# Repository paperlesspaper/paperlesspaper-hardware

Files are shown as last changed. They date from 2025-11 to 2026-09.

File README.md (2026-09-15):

### [paperlesspaper](https://paperlesspaper.de/en) e-Paper Photo Frame Hardware

Here you will find all source files of our PCB design and hardware CAD files used for the [paperlesspaper](https://paperlesspaper.de/en) ePaper photo frame which has a Spectra 6 color EInk display.

[Documentation about manufacturing the parts](https://docs.paperlesspaper.de/manufacturing/overview)

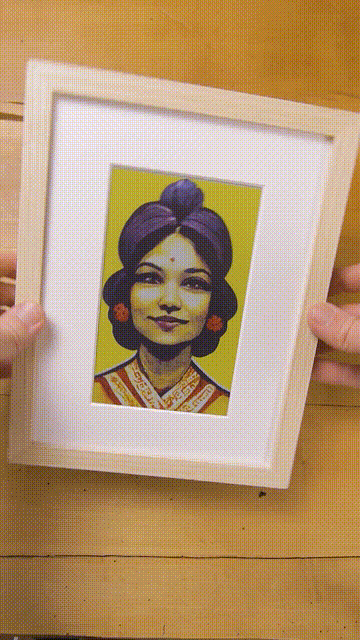
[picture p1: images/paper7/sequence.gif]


There is also a short [blog post](https://paperlesspaper.de/en/blog/open-hardware) available.

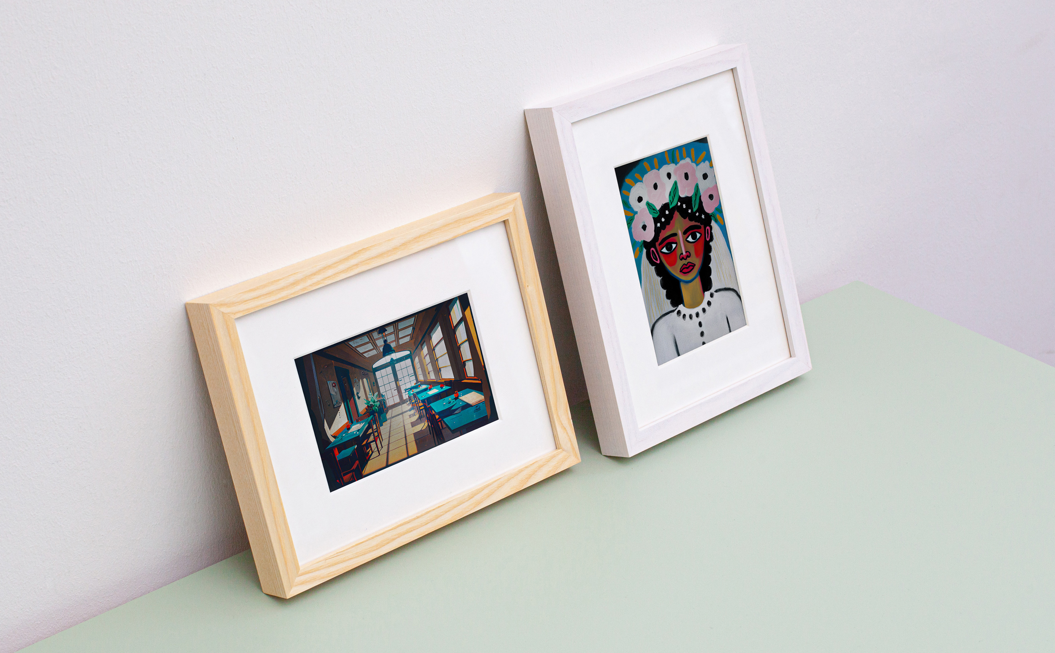
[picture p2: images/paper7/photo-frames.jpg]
pcb side by side (https://paperlesspaper.de/en)


### What you need

Software:

- [Autodesk Fusion 360](https://www.autodesk.com/de/education/edu-software/fusion) (free version is good enough, for everything except PCB)
- Adobe Illustrator (only for the laser of the backside)

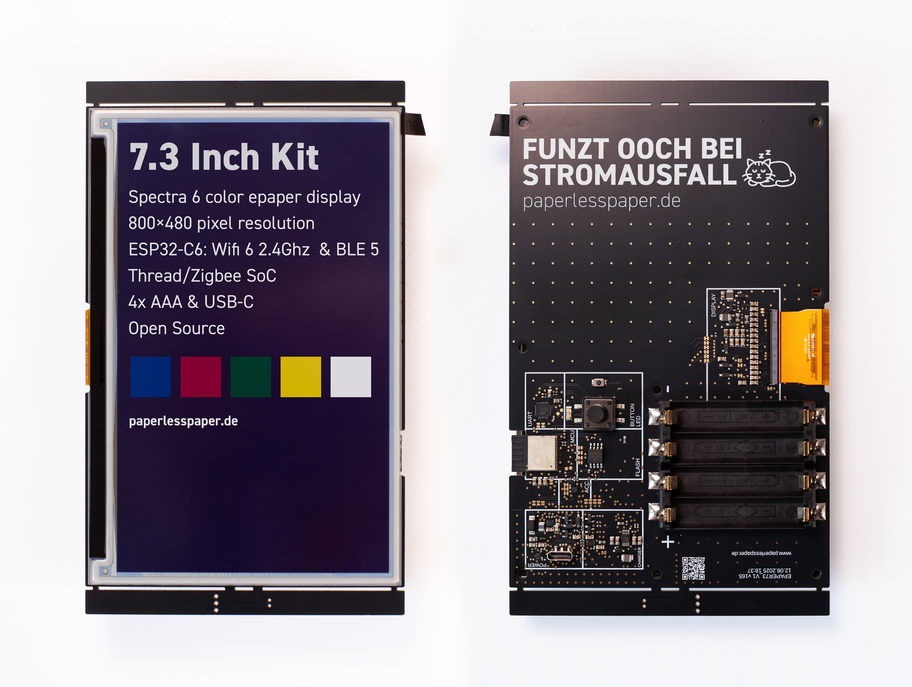
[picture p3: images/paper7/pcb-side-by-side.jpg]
pcb side by side


Manufacture:

- 3D printer (for battery holder and for fixtures/carriers)
- laser cutter (or CNC) for back panel of the photo frame
- manufacturer like JLCPCB for the PCB (more info soon)

Hardware:

- Standard picture-frame with turn buttons or spring clips

### Source files

| Model | Hardware files |
| --- | --- |
| Paper 7 / OpenPaper 7 | [paper7/](./paper7/) — PCB, Fusion CAD, fixtures, laser-cut files and STL parts |
| OpenPaper L (13.3-inch) | [paperl/](./paperl/) — Fusion assembly, PCB sources, manufacturing archive, laser-cut files and STL parts |

See the [OpenPaper L hardware guide](./paperl/README.md) for file descriptions, source versions and manufacturing notes.

### Paper 7 / OpenPaper 7

The following files can be found inside [/paper7](./paper7/).

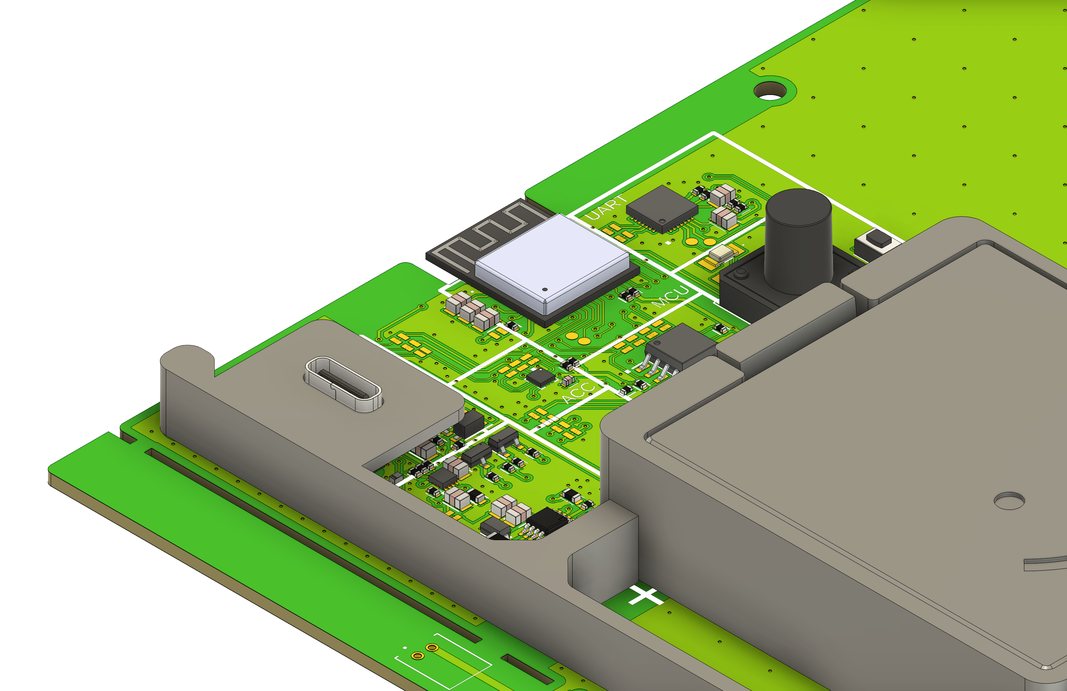
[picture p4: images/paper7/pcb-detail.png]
detail image of the pcb


#### [pcb/](./paper7/pcb/)

PCB design source files and manufacturing exports for the Paper 7 board.

- [EPAPER73_V2.fsch](./paper7/pcb/EPAPER73_V2.fsch) and [EPAPER73_V2.fbrd](./paper7/pcb/EPAPER73_V2.fbrd): schematic and board source files for Autodesk Fusion Electronics.
- [EPAPER73_V2_sch.jpg](./paper7/pcb/EPAPER73_V2_sch.jpg) and [EPAPER73_V2_pcb.jpg](./paper7/pcb/EPAPER73_V2_pcb.jpg): preview images of the schematic and PCB layout.
- [paper7_v2_gerber.zip](./paper7/pcb/paper7_v2_gerber.zip): Gerber and drill files for PCB fabrication, including copper, soldermask, silkscreen, solderpaste, profile and drill layers.
- [epaper-bom-V2.xlsx](./paper7/pcb/epaper-bom-V2.xlsx): bill of materials for PCB assembly.
- [epaper-pp-V2.xlsx](./paper7/pcb/epaper-pp-V2.xlsx): pick-and-place / component placement file for PCB assembly.
- [EPAPER73_V2.3mf](./paper7/pcb/EPAPER73_V2.3mf): 3D export of the PCB for mechanical checks and fit validation.

Use the Gerber zip together with the BOM and pick-and-place spreadsheet when ordering an assembled PCB. Use the `.fsch` and `.fbrd` files if you want to inspect or modify the design.

#### [paper-7-inside.f3z](./paper7/paper-7-inside.f3z)

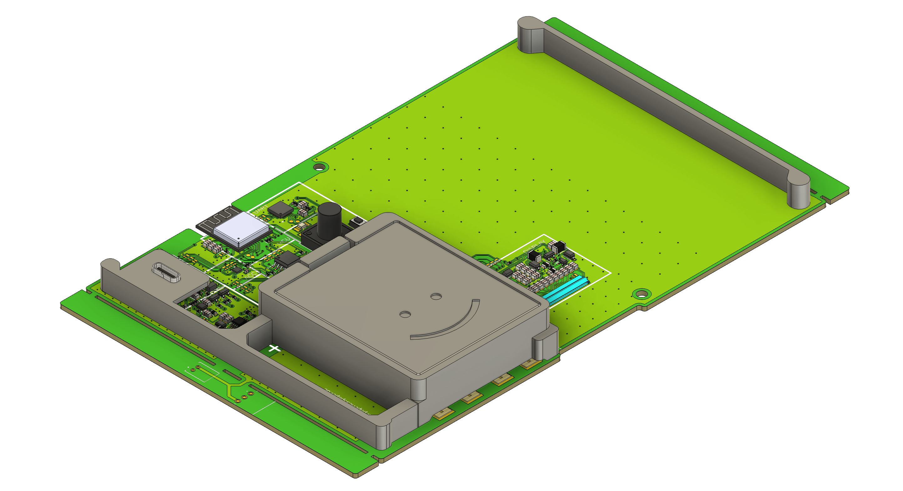
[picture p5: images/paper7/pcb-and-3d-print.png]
detail image of the pcb


The inner carrier (sub-frame) that the PCB attaches to. Contains the PCB and 3D printed parts for USB connector, battery holder and distance elements.

#### [paper-7-picture-frame.f3z](./paper7/paper-7-picture-frame.f3z)

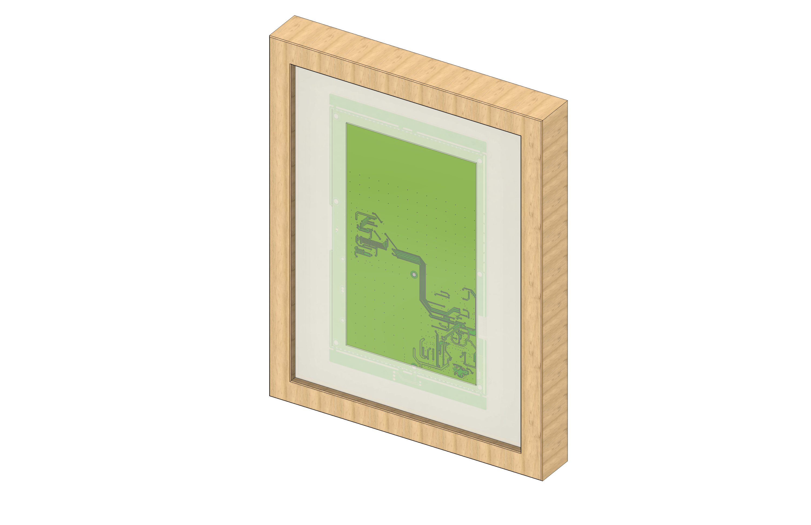
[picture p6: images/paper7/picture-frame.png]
detail image of the pcb


The picture frame. Used to create the laser cut on the backside. Fits the "inside".

#### [paper-7-passepartout-appliance-fixture.f3z](./paper7/paper7-passepartout-applicance-fixture.f3z)

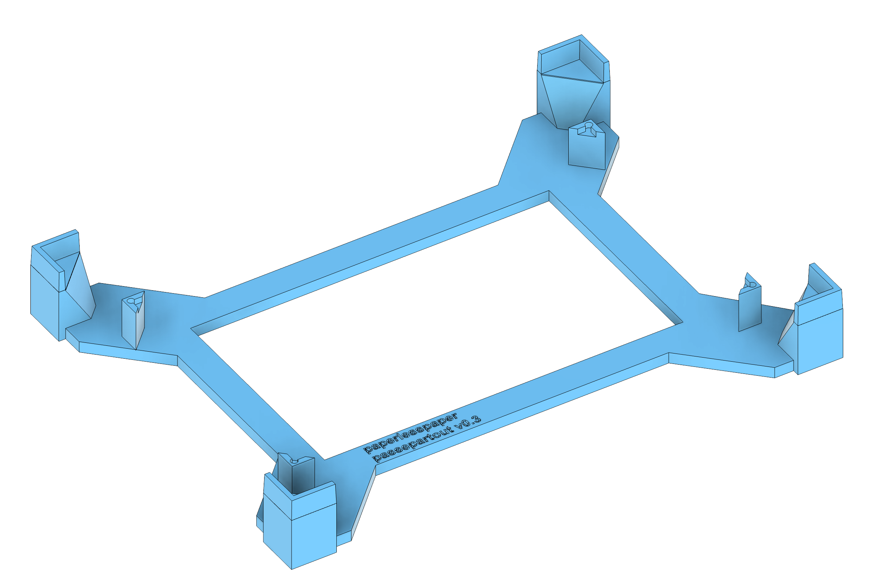
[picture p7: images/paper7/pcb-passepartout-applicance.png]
detail image of the pcb


A slimmer jig for aligning the display with a passe-partout / mat.
Ensures the visible window is perfectly centered and parallel.

#### [paper7-display-appliance-fixture.f3z](./paper7/paper7-display-appliance-fixture.f3z)

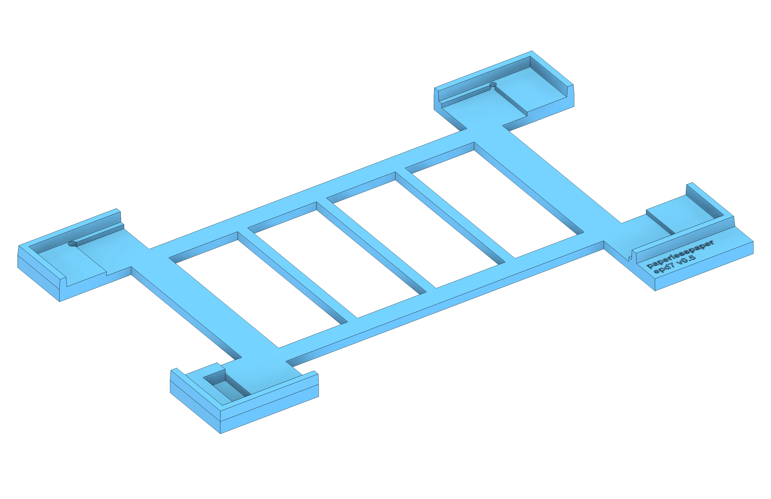
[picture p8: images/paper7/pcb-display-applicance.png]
detail image of the pcb


A jig to hold the display/appliance while you bond it. Keeps the panel centered relative to the frame opening.

#### [lasercut/Lasercut-back-generic.ai](./paper7/lasercut/Lasercut-back-generic.ai) and [.svg](./paper7/lasercut/Lasercut-back-generic.svg)

The lasercut source files to create the backside of the picture frame.

Color mapping: `red: cut`, `black: mark`, `green: ignore`

#### 3D print (battery compartment & spacers)

For the 3D printed files you can find the replacement parts also at [Makerworld](https://makerworld.com/de/models/1668788-paper-7-battery-compartment#profileId-1766474).
The recommended material is PETG. There are no screws needed. Only the battery cover needs to be glued for better durability. Use regular superglue to glue it.

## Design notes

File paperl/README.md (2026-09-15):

# OpenPaper L hardware

Hardware files for the 13.3-inch OpenPaper L e-Paper photo frame. This directory follows the [Paper 7 hardware](../paper7/) structure, with Fusion CAD, printable replacement parts, PCB sources and back-panel laser templates.

## Fusion CAD

| Front | Back (battery cover hidden) |
| --- | --- |
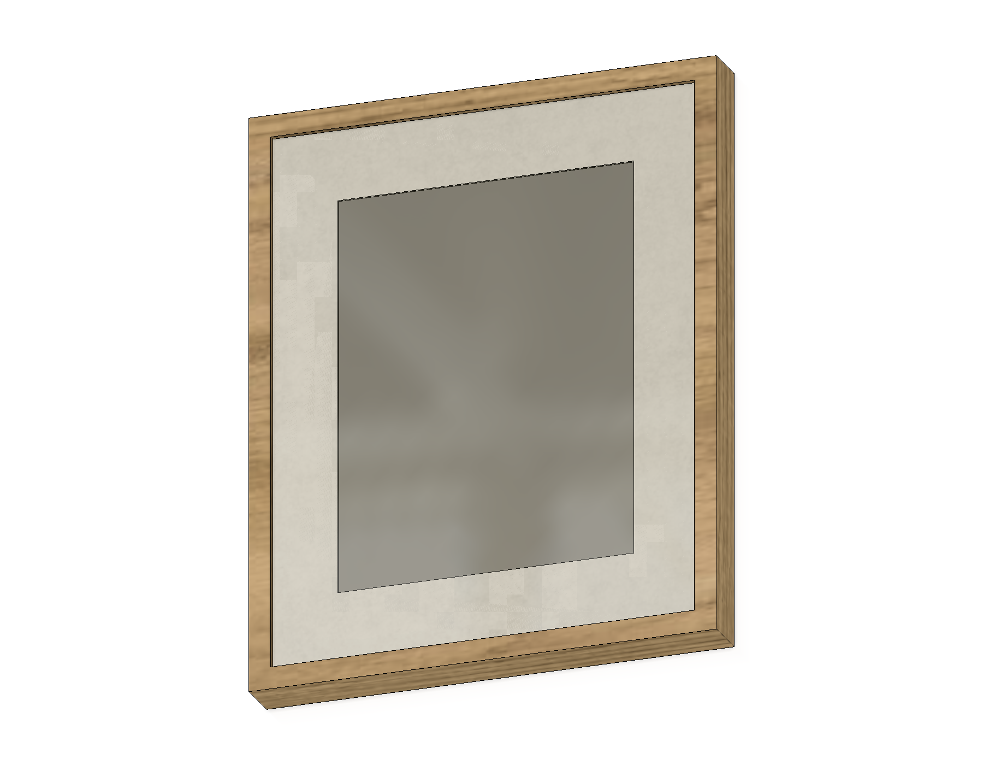
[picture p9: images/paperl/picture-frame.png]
OpenPaper L front
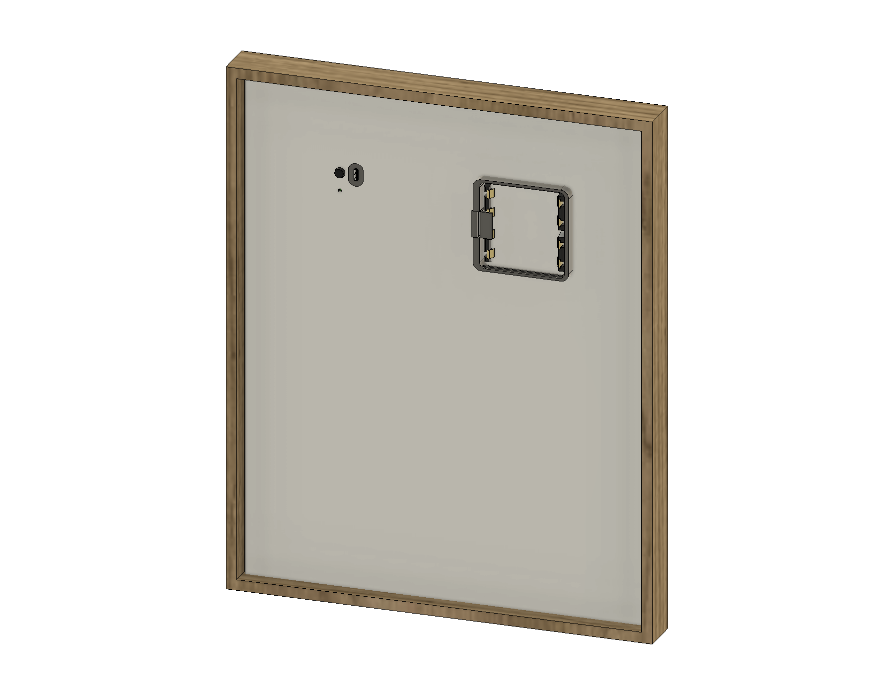
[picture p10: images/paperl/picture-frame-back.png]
OpenPaper L back
|  |  |

- [paper-l-picture-frame.f3z](./paper-l-picture-frame.f3z): complete **OpenPaper L Bilderrahmen** assembly, including the wooden frame, glass, passe-partout, back panel, internal carrier, PCB and display references.

Upload the `.f3z` archive through Fusion's data panel to import its linked designs together. The inner assembly is named **OpenPaper L inside 3**. It contains the battery compartment, cover, corner spacer, spring and USB holder. The display reference retains its original Fusion name, **DEK 13.3 inch panel**.

The archive was exported on **2026-09-14** after updating and saving the linked Fusion references:

| Fusion design | Version in the archive |
| --- | --- |
| OpenPaper L Bilderrahmen | 11 |
| OpenPaper L inside 3 | 10 |
| EPAPER133_V2 (3D PCB) | 8 |
| DEK 13.3 inch panel | 4 |

## 3D print

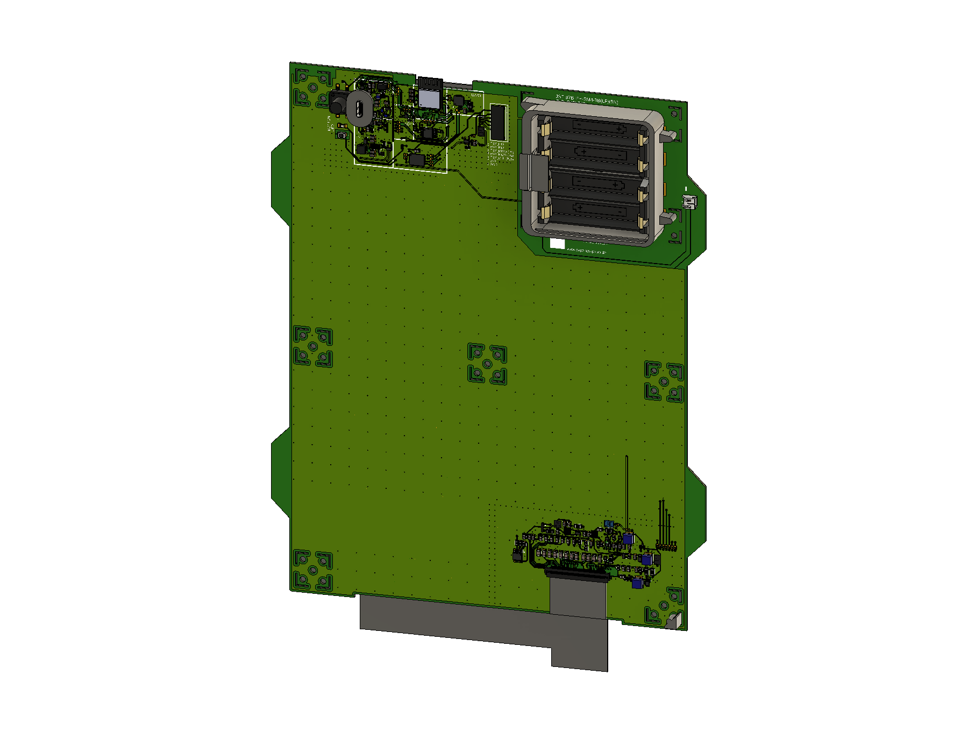
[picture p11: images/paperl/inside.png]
OpenPaper L inner assembly


The [stl/](./stl/) files were exported from the above picture-frame assembly in **millimetres**, using binary STL and Fusion's high mesh refinement. Each file contains one part, without the hidden battery-compartment context body.

| File | Fusion component | Bounding box in mm (X × Y × Z) |
| --- | --- | --- |
| [Battery compartment](./stl/paper-l-BatteryCompartment.stl) | Batteriefach v2  | 82.196 × 71.700 × 19.500 |
| [Battery cover](./stl/paper-l-BatteryCover.stl) | Deckel | 65.284 × 64.699 × 3.200 |
| [Corner spacer](./stl/paper-l-Corner.stl) | Corner | 6.605 × 6.605 × 10.000 |
| [Spring](./stl/paper-l-Spring.stl) | Spring | 15.500 × 19.800 × 9.500 |
| [USB holder](./stl/paper-l-USBHolder.stl) | USB holder | 14.300 × 20.080 × 6.500 |

Choose orientation, material and the required number of copies in your slicer for the assembly being built. The dimensions above describe the CAD coordinate orientation, not a recommended print orientation.

## PCB

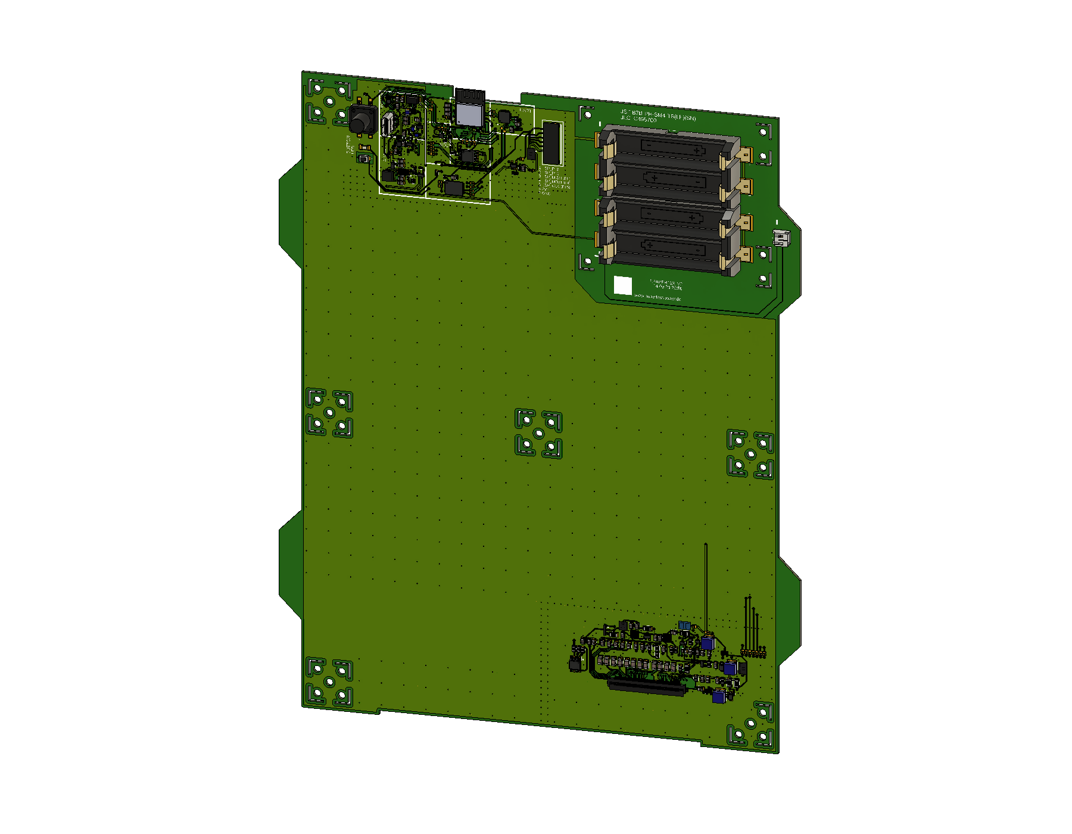
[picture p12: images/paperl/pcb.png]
OpenPaper L PCB


- [EPAPER133_V2.fsch](./pcb/EPAPER133_V2.fsch): native Fusion Electronics schematic, version 5.
- [EPAPER133_V2.fbrd](./pcb/EPAPER133_V2.fbrd): native Fusion Electronics board, version 13, matching the 2D-board reference recorded in the exported 3D PCB.
- [EPAPER133_V2.3mf](./pcb/EPAPER133_V2.3mf): 3D PCB mesh exported from the updated picture-frame assembly (PCB version 8).
- [Schematic preview](../images/paperl/fsch.png) and [board preview](../images/paperl/fbrd.png): embedded previews from the respective native source files.
- [manufacturing-2026-08-17/](./pcb/manufacturing-2026-08-17/): the existing fabrication batch, containing [Gerber/drill files](./pcb/manufacturing-2026-08-17/paper-l-v2-gerber.zip), [BOM](./pcb/manufacturing-2026-08-17/EPAPER133_V2.csv) and [front-side pick-and-place data](./pcb/manufacturing-2026-08-17/PnP_EPAPER133_V2_front.csv).

## Laser-cut back panel

The [lasercut/](./lasercut/) directory contains the existing production templates, with separate machine layouts:

| Layout | Illustrator source | SVG | SVG canvas |
| --- | --- | --- | --- |
| Zing | [AI](./lasercut/zing/Lasercut-back-zing.ai) | [SVG](./lasercut/zing/Lasercut-back-zing.svg) | 610 × 400.54 mm |
| Lasersaur | [AI](./lasercut/lasersaur/Lasercut-back-lasersaur.ai) | [SVG](./lasercut/lasersaur/Lasercut-back-lasersaur.svg) | 1100 × 570 mm |

Color mapping: **red = cut**, **black = mark**, **green = ignore / alignment**. These layouts position cutouts and markings on existing frame backs; the canvas size is the machine layout size, not the size of a single back panel. Preserve the SVG's physical units when importing.

The laser files are the existing May 2026 production files. Check the battery and USB openings against your frame back before cutting. Machine power/speed presets are not included.

## Source provenance

| Repository files | Original source |
| --- | --- |
| Fusion archive and STL files | Autodesk Fusion: `OpenPaper L Bilderrahmen`, exported 2026-09-14 after reference update |
| PCB `.fsch` / `.fbrd` | Fusion's local native source snapshots, schematic v5 and board v13; the latter is referenced by the archived 3D PCB |
| August Gerber, BOM and pick-and-place files | `Hardware/PCB/CAM133/V2/EPAPER133_V2_2026-08-17.zip` |
| Zing AI | `OpenPaper L/Aktuell Zing/OpenPaper L Rückseite-Zing2.ai` (2026-05-28) |
| Zing SVG | `OpenPaper L/Aktuell Zing/OpenPaper L Rückseite-Zing.svg` (2026-05-26) |
| Lasersaur AI | `OpenPaper L/Aktuell Lasersaur/Laservorlage-Saur3.ai` (2026-05-28) |
| Lasersaur SVG | `OpenPaper L/Aktuell Lasersaur/Laservorlage-Saur2.svg` (2026-05-26) |

For the existing manufacturing overview, see the [project documentation](https://docs.paperlesspaper.de/manufacturing/overview).

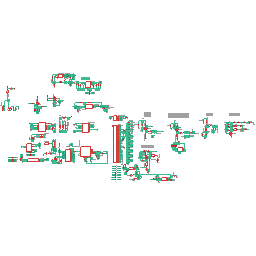
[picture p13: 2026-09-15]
images/paperl/fsch.png

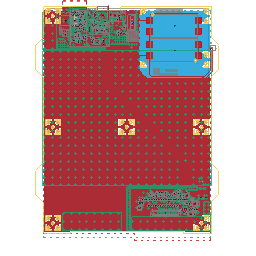
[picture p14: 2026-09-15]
images/paperl/fbrd.png

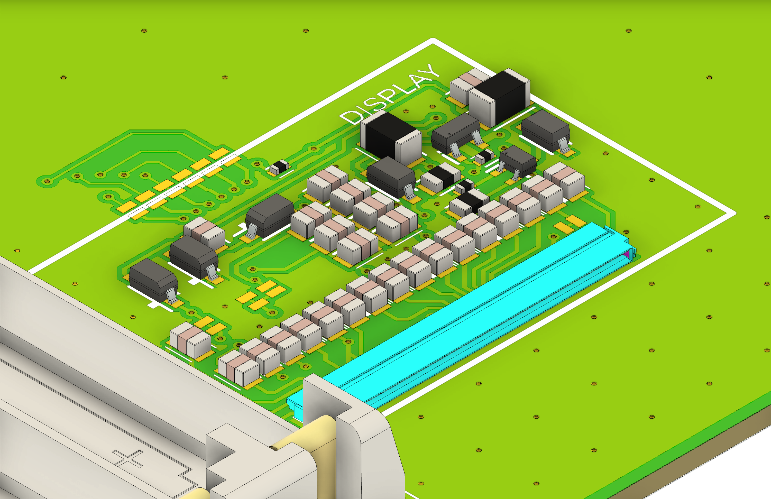
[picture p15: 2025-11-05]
images/paper7/pcb-detail-display.png

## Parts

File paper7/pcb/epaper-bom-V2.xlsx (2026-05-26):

Qty | Comment | Device | Footprint | Designator | JLCPCB Part # | Description
16 | 10uF 25V 0805 | C_CHIP-0805(2012-METRIC) | CAPC2012X110 | C1, C3, C8, C11, C12, C13, C14, C15, C16, C30, C31, C33, C38, C46, C49, C50 | C15850 | Capacitor - Generic
1 | 470nF 25V 0805 | C_CHIP-0805(2012-METRIC) | CAPC2012X110 | C10 | C13967 | Capacitor - Generic
6 | 1uF 50V 0805 | C_CHIP-0805(2012-METRIC) | CAPC2012X110 | C17, C18, C20, C21, C22, C23 | C28323 | Capacitor - Generic
1 | 2.2uF 25V 0805 | C_CHIP-0805(2012-METRIC) | CAPC2012X110 | C19 | C377773 | Capacitor - Generic
5 | 1uF 25V 0805 | C_CHIP-0805(2012-METRIC) | CAPC2012X110 | C2, C6, C39, C40, C47 | C28323 | Capacitor - Generic
1 | 470nF 50V 0805 | C_CHIP-0805(2012-METRIC) | CAPC2012X110 | C24 | C13967 | Capacitor - Generic
1 | 10uF 50V 0805 | C_CHIP-0805(2012-METRIC) | CAPC2012X110 | C26 | C440198 | Capacitor - Generic
4 | 100nF 25V 0402 | C_CHIP-0402(1005-METRIC) | CAPC1005X60 | C35, C42, C44, C48 | C307331 | Capacitor - Generic
7 | 4.7uF 25V 0805 | C_CHIP-0805(2012-METRIC) | CAPC2012X110 | C4, C5, C9, C28, C29, C36, C37 | C1779 | Capacitor - Generic
2 | 1nF 25V 0402 | C_CHIP-0402(1005-METRIC) | CAPC1005X60 | C41, C45 | C1523 | Capacitor - Generic
5 | 100nF 50V 0805 | C_CHIP-0805(2012-METRIC) | CAPC2012X110 | C7, C25, C27, C32, C34 | C28233 | Capacitor - Generic
3 | LESD5D5.0CT1G | LESD5D5.0CT1G | LESD5D50CT1G | D1, D2, D3 | C5199850 | Transient Voltage Suppressors for ESD Protection
1 | PMEG2010AEH | PMEG2010AEH | SODFL3516X120N | D10 | C110921 | Diode Schottky 20V 1A,PMEG2010AEH NXP PMEG2010AEH Schottky Diode, 1A, 20V, 2-Pin SOD123F
1 | SS34 | SS34 | DIOM5327X244N | D12 | C8678 | SMD Schottky Diode
2 | CUS08F30 | CUS08F30 | CUS357H3F | D4, D13 | C27636112
4 | MBR0530T1G | MBR0530 | SOD3716X135N | D5, D6, D7, D8 | C82046 | Compact Surface Mount Package with The Same Footprint as Mini-melf; Schottky Rectifier, 0.5A, 30V in SOD-123 Package
2 | BH-AAA-B5AA001 | 1078 | 1078 | H1, H2 | C964881 | Cylindrical Battery Contacts, Clips, Holders & Springs AAA dual holder w/ coil Spring SMT
1 | W25Q128JVSIQ | W25Q128JVSIQ | SOIC127P790X216-8N | IC1 | C97521 | 128M-bit Serial Flash Memory with uniform 4KB sectors and Dual/Quad SPI
1 | CP2102N-A02-GQFN28R | CP2102N-A02-GQFN28R | QFN50P500X500X80-29N | IC2 | C964632 | USB Interface IC USB to UART bridge - QFN28
1 | BQ25172DSGR | BQ25172DSGR | SON50P200X200X80-9N | IC4 | C5189434 | Battery Management 0.8-A, one- to six-cell NiMH stand-alone linear charger in a QFN package
1 | DMP2035U | DMP2035U | SOT96P240X115-3N | IC5 | C110499 | MOSFET, P CH, ESD,-20V,-3.6A, SOT23
1 | TPS61085DGKR | TPS61085DGKR | SOP65P490X110-8N | IC6 | C113659 | 18.5V, 2A, 650kHz / 1.2MHz Step-Up DC-DC Converter w/ Forced PWM Mode
1 | U263-241N-4BQC02 | U263-241N-4BQC02 | U263241N4BQC02 | J1 | C2689742 | 3.1TYPE-C connector female 24P upright
1 | FPC-05FB-50PH20 | FPC-05FB-50PH20 | FPC05FB50PH20 | J5 | C2856838
2 | 10uH/1A (20%) | CUSTOMINDUCTORSBCIHP0420SC-100M | BCIHP0420SC-100M | U$1, U$3 | C2921170 | Inductor Fixed - Generic
1 | 2.2uH/1A (20%) LQM2HPN2R2MG0L | L_CHIP-1008(2520-METRIC) | INDC2520X120N | L3 | C86092 | Inductor Fixed - Generic
1 | 3.3uH 1.5A | CUSTOMINDUCTORSSL0420-3R3M | SL0420-3R3M | U$2 | C22463807 | Inductor Fixed - Generic
1 | KPTD-3216SGC | KPTD-3216SGC | KPTD3216SGC | LED1 | C19171273 | LED super bright green 568nm;105mW;water clear;3.2x1.6mm;SMT;reel
1 | DMP3056L-7 | DMP3056L-7 | SOT-23 | Q6 | C150724
1 | SI2301CDS-T1-E3 | SI2301CDS-T1-E3 | SOT95P237X112-3N | Q1 | C145226 | VISHAY - SI2301CDS-T1-E3 - Power MOSFET, P Channel, 20 V, 3.1 A, 0.11 ohm, SOT-23, Surface Mount
1 | SI1308EDL-T1-GE3 | SI1308EDL-T1-GE3 | SOT65P210X110-3N | Q2 | C469327 | MOSFET N-Ch 30V 1.5A TrenchFET SC70 Vishay Si1308EDL-T1-GE3 N-channel MOSFET Transistor, 1.5 A, 30 V, 3-Pin SC-70
2 | 220mO 0805 | R_CHIP-0805(2012-METRIC) | RESC2012X65 | R16, R19 | C2934262 | Resistor Fixed - Generic
2 | 1MO 0402 | R_CHIP-0402(1005-METRIC) | RESC1005X40 | R17, R18 | C26083 | Resistor Fixed - Generic
1 | 1KO 0402 | R_CHIP-0402(1005-METRIC) | RESC1005X40 | R2 | C11702 | Resistor Fixed - Generic
1 | 270kO 0402 | R_CHIP-0402(1005-METRIC) | RESC1005X40 | R21 | C25770 | Resistor Fixed - Generic
2 | 100KO 0402 | R_CHIP-0402(1005-METRIC) | RESC1005X40 | R20, R22 | C25741 | Resistor Fixed - Generic
1 | 1.2kO 0603 | R_CHIP-0603 |  | R24 | C22765 | Resistor Fixed - Generic
1 | 11KO 0402 | R_CHIP-0402(1005-METRIC) | RESC1005X40 | R25 | C25749 | Resistor Fixed - Generic
1 | 36KO 0402 | R_CHIP-0402(1005-METRIC) | RESC1005X40 | R26 | C43676 | Resistor Fixed - Generic
1 | 47KO 0402 | R_CHIP-0402(1005-METRIC) | RESC1005X40 | R3 | C25792 | Resistor Fixed - Generic
2 | 510KO 0603 | R_CHIP-0603(1608-METRIC) | RESC1608X60 | R39, R40 | C23192 | Resistor Fixed - Generic
1 | 22KO 0402 | R_CHIP-0402(1005-METRIC) | RESC1005X40 | R4 | C25768 | Resistor Fixed - Generic
1 | 2kO 0603 | R_CHIP-0603(1608-METRIC) | RESC1608X60 | R41 | C22975 | Resistor Fixed - Generic
1 | 18KO 0402 | R_CHIP-0402(1005-METRIC) | RESC1005X40 | R42 | C25762 | Resistor Fixed - Generic
1 | 75kO 0603 | R_CHIP-0603 |  | R43 | C23242 | Resistor Fixed - Generic
2 | 820KO 0402 | R_CHIP-0402(1005-METRIC) | RESC1005X40 | R5, R6 | C67558 | Resistor Fixed - Generic
1 | 30KO 0402 | R_CHIP-0402(1005-METRIC) | RESC1005X40 | R7 | C25776 | Resistor Fixed - Generic
14 | 10KO 0402 | R_CHIP-0402(1005-METRIC) | RESC1005X40 | R8, R9, R10, R11, R12, R13, R14, R15, R28, R29, R30, R31, R34, R35 | C25744 | Resistor Fixed - Generic
1 | TS-1088-AR02016 | TS-1088-AR02016 | TS1088AR02016 | S1 | C720477 | Tact Switch
1 | TS-1103S-C-U (C318914) | TS-1103S-C-U | TS1103SCU | S3 | C318914 | tact switch 12x12X14 patch cylindrical black knob 260GF stainless steel shrapnel
1 | ESP32-C6-MINI-1-N4 | ESP32-C6-MINI-1-N4 | XCVR_ESP32-C6-MINI-1-N4 | U1 | C5736265 | Check availability
1 | FUSB303TMX | FUSB303TMX | X2QFN12 | U2 | C603072 | Check availability
1 | TPS62840DLCR | TPS62840DLCR | SON50P200X150X100-8N | U3 | C2071859 | Check availability
1 | KXTJ3-1057 | KXTJ3-1057 | KIONIX_KXTJ3-1057 | U4 | C442603 | Check availability
1 | BZT52C27 | BZT52C27 | SOD3716X125N | Z1 | C511889 | SOD-123 Plastic-Encapsulate Diodes

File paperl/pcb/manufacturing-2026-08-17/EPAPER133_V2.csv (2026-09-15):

Qty | Value | Device | Package | Parts | Description | ARROW_PART_NUMBER | ARROW_PRICE-STOCK | AVAILABILITY | CATEGORY | CHECK_PRICES | DESCRIPTION | HEIGHT | MANUFACTURER | MANUFACTURER_NAME | MANUFACTURER_PART_NUMBER | MAXIMUM_PACKAGE_HEIGHT | MF | MOUSER_PART_NUMBER | MOUSER_PRICE-STOCK | MP | MPN | OPERATING_TEMP | PACKAGE | PARTREV | PART_STATUS | POPULARITY | PRICE | RATING | ROHS_COMPLIANT | SERIES | SIMULATION_DATA | SNAPEDA_LINK | SNAPEDA_PN | STANDARD | SUB-CATEGORY | THERMALLOSS | TOLERANCE | TP_SIGNAL_NAME | TYPE | VOLTAGE_RATING
3 | 0.2O 1206 | R_CHIP-1206(3216-METRIC) | RESC3216X70 | R18, R23, R32 | Resistor Fixed - Generic |  |  |  | Resistor |  |  |  |  |  |  |  |  |  |  |  |  |  |  |  |  |  |  |  |  |  |  |  |  |  | Fixed
1 | 0O 1206 | R_CHIP-1206(3216-METRIC) | RESC3216X70 | R27 | Resistor Fixed - Generic |  |  |  | Resistor |  |  |  |  |  |  |  |  |  |  |  |  |  |  |  |  |  |  |  |  |  |  |  |  |  | Fixed
1 | 1.2KO 0603 | R_CHIP-0603(1608-METRIC) | RESC1608X60 | R24 | Resistor Fixed - Generic |  |  |  | Resistor |  |  |  |  |  |  |  |  |  |  |  |  |  |  |  |  |  |  |  |  |  |  |  |  |  | Fixed
1 | 1.5kO 0805 | R_CHIP-0805(2012-METRIC) | RESC2012X65 | R50 | Resistor Fixed - Generic |  |  |  | Resistor |  |  |  |  |  |  |  |  |  |  |  |  |  |  |  |  |  |  |  |  |  |  |  |  |  | Fixed
4 | 100KO 0402 | R_CHIP-0402(1005-METRIC) | RESC1005X40 | R20, R37, R39, R57 | Resistor Fixed - Generic |  |  |  | Resistor |  |  |  |  |  |  |  |  |  |  |  |  |  |  |  |  |  |  |  |  |  |  |  |  |  | Fixed
1 | 100kO 0805 | R_CHIP-0805(2012-METRIC) | RESC2012X65 | R49 | Resistor Fixed - Generic |  |  |  | Resistor |  |  |  |  |  |  |  |  |  |  |  |  |  |  |  |  |  |  |  |  |  |  |  |  |  | Fixed
3 | 100nF 25V 0402 | C_CHIP-0402(1005-METRIC) | CAPC1005X60 | C35, C44, C48 | Capacitor - Generic |  |  |  | Capacitor
7 | 100nF 50V 0805 | C_CHIP-0805(2012-METRIC) | CAPC2012X110 | C7, C11, C13, C14, C18, C20, C26 | Capacitor - Generic |  |  |  | Capacitor
2 | 1012 | 1012 | BAT_1012 | BT1, BT2 |  |  |  |  |  |  |  |  | Keystone |  |  | 15.11mm |  |  |  |  |  |  |  | C |  |  |  |  |  |  |  |  | 1012 | Manufacturer Recommendations
14 | 10KO 0402 | R_CHIP-0402(1005-METRIC) | RESC1005X40 | R8, R9, R10, R11, R12, R13, R14, R15, R28, R29, R30, R34, R35, R36 | Resistor Fixed - Generic |  |  |  | Resistor |  |  |  |  |  |  |  |  |  |  |  |  |  |  |  |  |  |  |  |  |  |  |  |  |  | Fixed
9 | 10uF 25V 0805 | C_CHIP-0805(2012-METRIC) | CAPC2012X110 | C1, C3, C8, C37, C46, C49, C50, C66, C67 | Capacitor - Generic |  |  |  | Capacitor
5 | 10uF 50V 0805 | C_CHIP-0805(2012-METRIC) | CAPC2012X110 | C10, C12, C17, C55, C64 | Capacitor - Generic |  |  |  | Capacitor
1 | 110kO 0805 | R_CHIP-0805(2012-METRIC) | RESC2012X65 | R47 | Resistor Fixed - Generic |  |  |  | Resistor |  |  |  |  |  |  |  |  |  |  |  |  |  |  |  |  |  |  |  |  |  |  |  |  |  | Fixed
1 | 113KO 0402 | R_CHIP-0402(1005-METRIC) | RESC1005X40 | R22 | Resistor Fixed - Generic |  |  |  | Resistor |  |  |  |  |  |  |  |  |  |  |  |  |  |  |  |  |  |  |  |  |  |  |  |  |  | Fixed
1 | 11KO 0402 | R_CHIP-0402(1005-METRIC) | RESC1005X40 | R25 | Resistor Fixed - Generic |  |  |  | Resistor |  |  |  |  |  |  |  |  |  |  |  |  |  |  |  |  |  |  |  |  |  |  |  |  |  | Fixed
3 | 15 uH SWPA5040S150MT | SWPA5040S150MT | INDPM5050X400N | U$1, U$3, U$5 | 1uH +/-30% 4.9A 16m SMD,5.0x5.0x4.0mm Power Inductors RoHS |  |  |  |  |  | 1uH +/-30% 4.9A 16m SMD | 5.0x5.0x4.0mm Power Inductors RoHS | 4mm |  | SUNLORD | SWPA5040S1R0NT
1 | 16kO 0805 | R_CHIP-0805(2012-METRIC) | RESC2012X65 | R44 | Resistor Fixed - Generic |  |  |  | Resistor |  |  |  |  |  |  |  |  |  |  |  |  |  |  |  |  |  |  |  |  |  |  |  |  |  | Fixed
1 | 18KO 0402 | R_CHIP-0402(1005-METRIC) | RESC1005X40 | R42 | Resistor Fixed - Generic |  |  |  | Resistor |  |  |  |  |  |  |  |  |  |  |  |  |  |  |  |  |  |  |  |  |  |  |  |  |  | Fixed
1 | 1KO 0402 | R_CHIP-0402(1005-METRIC) | RESC1005X40 | R2 | Resistor Fixed - Generic |  |  |  | Resistor |  |  |  |  |  |  |  |  |  |  |  |  |  |  |  |  |  |  |  |  |  |  |  |  |  | Fixed
3 | 1MO 0805 | R_CHIP-0805(2012-METRIC) | RESC2012X65 | R17, R19, R31 | Resistor Fixed - Generic |  |  |  | Resistor |  |  |  |  |  |  |  |  |  |  |  |  |  |  |  |  |  |  |  |  |  |  |  |  |  | Fixed
2 | 1nF 25V 0402 | C_CHIP-0402(1005-METRIC) | CAPC1005X60 | C45, C63 | Capacitor - Generic |  |  |  | Capacitor
6 | 1uF 25V 0805 | C_CHIP-0805(2012-METRIC) | CAPC2012X110 | C2, C6, C39, C40, C47, C65 | Capacitor - Generic |  |  |  | Capacitor
2 | 1uF 50V 0805 | C_CHIP-0805(2012-METRIC) | CAPC2012X110 | C19, C22 | Capacitor - Generic |  |  |  | Capacitor
2 | 2.2O 1206 | R_CHIP-1206(3216-METRIC) | RESC3216X70 | R45, R48 | Resistor Fixed - Generic |  |  |  | Resistor |  |  |  |  |  |  |  |  |  |  |  |  |  |  |  |  |  |  |  |  |  |  |  |  |  | Fixed
2 | 200kO 0805 | R_CHIP-0805(2012-METRIC) | RESC2012X65 | R33, R54 | Resistor Fixed - Generic |  |  |  | Resistor |  |  |  |  |  |  |  |  |  |  |  |  |  |  |  |  |  |  |  |  |  |  |  |  |  | Fixed
1 | 220nF 50V 0805 | C_CHIP-0805(2012-METRIC) | CAPC2012X110 | C29 | Capacitor - Generic |  |  |  | Capacitor
1 | 22KO 0402 | R_CHIP-0402(1005-METRIC) | RESC1005X40 | R4 | Resistor Fixed - Generic |  |  |  | Resistor |  |  |  |  |  |  |  |  |  |  |  |  |  |  |  |  |  |  |  |  |  |  |  |  |  | Fixed
12 | 22uF 25V 1206 | C_CHIP-1206(3216-METRIC) | CAPC3216X135 | C30, C31, C32, C33, C34, C41, C42, C43, C51, C52, C53, C54 | Capacitor - Generic |  |  |  | Capacitor
1 | 24.9KO 0402 | R_CHIP-0402(1005-METRIC) | RESC1005X40 | R21 | Resistor Fixed - Generic |  |  |  | Resistor |  |  |  |  |  |  |  |  |  |  |  |  |  |  |  |  |  |  |  |  |  |  |  |  |  | Fixed
1 | 2KO 0805 | R_CHIP-0805(2012-METRIC) | RESC2012X65 | R16 | Resistor Fixed - Generic |  |  |  | Resistor |  |  |  |  |  |  |  |  |  |  |  |  |  |  |  |  |  |  |  |  |  |  |  |  |  | Fixed
1 | 2kO 0603 | R_CHIP-0603(1608-METRIC) | RESC1608X60 | R41 | Resistor Fixed - Generic |  |  |  | Resistor |  |  |  |  |  |  |  |  |  |  |  |  |  |  |  |  |  |  |  |  |  |  |  |  |  | Fixed
1 | 3.3pF 10V 0402 | C_CHIP-0402(1005-METRIC) | CAPC1005X60 | C38 | Capacitor - Generic |  |  |  | Capacitor
1 | 3.3uH 1.5A | CUSTOMINDUCTORSSL0420-3R3M | SL0420-3R3M | U$2
1 | 3.9KO 0603 | R_CHIP-0603(1608-METRIC) | RESC1608X60 | R40 | Resistor Fixed - Generic |  |  |  | Resistor |  |  |  |  |  |  |  |  |  |  |  |  |  |  |  |  |  |  |  |  |  |  |  |  |  | Fixed
1 | 30KO 0402 | R_CHIP-0402(1005-METRIC) | RESC1005X40 | R7 | Resistor Fixed - Generic |  |  |  | Resistor |  |  |  |  |  |  |  |  |  |  |  |  |  |  |  |  |  |  |  |  |  |  |  |  |  | Fixed
1 | 36KO 0402 | R_CHIP-0402(1005-METRIC) | RESC1005X40 | R26 | Resistor Fixed - Generic |  |  |  | Resistor |  |  |  |  |  |  |  |  |  |  |  |  |  |  |  |  |  |  |  |  |  |  |  |  |  | Fixed
4 | 4.3kO 0805 | R_CHIP-0805(2012-METRIC) | RESC2012X65 | R46, R51, R52, R53 | Resistor Fixed - Generic |  |  |  | Resistor |  |  |  |  |  |  |  |  |  |  |  |  |  |  |  |  |  |  |  |  |  |  |  |  |  | Fixed
8 | 4.7uF 25V 0805 | C_CHIP-0805(2012-METRIC) | CAPC2012X110 | C4, C5, C9, C15, C16, C27, C36, C56 | Capacitor - Generic |  |  |  | Capacitor
1 | 4.7uF 50V 0805 | C_CHIP-0805(2012-METRIC) | CAPC2012X110 | C21 | Capacitor - Generic |  |  |  | Capacitor
6 | 470nF 50V 0805 | C_CHIP-0805(2012-METRIC) | CAPC2012X110 | C24, C25, C28, C57, C58, C59 | Capacitor - Generic |  |  |  | Capacitor
1 | 47KO 0402 | R_CHIP-0402(1005-METRIC) | RESC1005X40 | R3 | Resistor Fixed - Generic |  |  |  | Resistor |  |  |  |  |  |  |  |  |  |  |  |  |  |  |  |  |  |  |  |  |  |  |  |  |  | Fixed
1 | 47nF 50V 0805 | C_CHIP-0805(2012-METRIC) | CAPC2012X110 | C23 | Capacitor - Generic |  |  |  | Capacitor
1 | 505110-6091 | 505110-6091 | 5051106091 | J5 | Easy-On FFC/FPC Connector, 0.50mm Pitch, FD19 Series, Right-Angle, Bottom Contact, 1.90mm Height, Circuits, Gold over Nickel Plating |  |  |  |  |  | Easy-On FFC/FPC Connector | 0.50mm Pitch | FD19 Series | Right-Angle | Bottom Contact | 1.90mm Height | Circuits | Gold over Nickel Plating | 2.1mm |  | Molex | 505110-6091 |  |  | 538-505110-6091 | https://www.mouser.co.uk/ProductDetail/Molex/505110-6091?qs=fSIr1QPo%2F%2FQRD6rm5ZTYDw%3D%3D
1 | 560KO 0402 | R_CHIP-0402(1005-METRIC) | RESC1005X40 | R38 | Resistor Fixed - Generic |  |  |  | Resistor |  |  |  |  |  |  |  |  |  |  |  |  |  |  |  |  |  |  |  |  |  |  |  |  |  | Fixed
1 | 75kO 0603 | R_CHIP-0603(1608-METRIC) | RESC1608X60 | R43 | Resistor Fixed - Generic |  |  |  | Resistor |  |  |  |  |  |  |  |  |  |  |  |  |  |  |  |  |  |  |  |  |  |  |  |  |  | Fixed
2 | 820KO 0402 | R_CHIP-0402(1005-METRIC) | RESC1005X40 | R5, R6 | Resistor Fixed - Generic |  |  |  | Resistor |  |  |  |  |  |  |  |  |  |  |  |  |  |  |  |  |  |  |  |  |  |  |  |  |  | Fixed
1 | B7B-PH-SM4-TB_LF__SN_ | B7B-PH-SM4-TB_LF__SN_ | B7BPHSM4TBLFSN | J2 | JST PH Series 2 mm Pitch 7 Position SMT Single Row Top Entry Shrouded Header |  |  |  |  |  | JST PH Series 2 mm Pitch 7 Position SMT Single Row Top Entry Shrouded Header | 6.6mm |  | JST (JAPAN SOLDERLESS TERMINALS) | B7B-PH-SM4-TB(LF)(SN) |  |  | 306-B7BPHSM4TBLFSN | https://www.mouser.co.uk/ProductDetail/JST-Commercial/B7B-PH-SM4-TBLFSN?qs=dbcCsuKDzFUgZwsE63VugA%3D%3D
3 | BAT54S | BAT54S | SOT95P240X120-3N | D8, D9, D11 | Obsolete - Schottky Barrier Diode | BAT54S | https://www.arrow.com/en/products/bat54s/on-semiconductor |  |  |  | Obsolete - Schottky Barrier Diode | 1.2mm |  | onsemi | BAT54S |  |  | 512-BAT54S | https://www.mouser.co.uk/ProductDetail/onsemi-Fairchild/BAT54S?qs=WjC1ij5gCHN3lvcpF9iNwQ%3D%3D
1 | BLM18PG221SH1D | BLM18PG221SH1D | BLM18SP221SN1B | FB2 | Murata Power Solutions Ferrite Bead (Chip Bead), 1.6 x 0.8 x 0.8mm (1608), 220 impedance at 100 MHz | BLM18PG221SH1D | https://www.arrow.com/en/products/blm18pg221sh1d/murata-manufacturing?utm_currency=USD&region=europe |  |  |  | Murata Power Solutions Ferrite Bead (Chip Bead) | 1.6 x 0.8 x 0.8mm (1608) | 220 impedance at 100 MHz | 0.95mm |  | Murata Electronics | BLM18PG221SH1D |  |  | 81-BLM18PG221SH1D | https://www.mouser.co.uk/ProductDetail/Murata-Electronics/BLM18PG221SH1D?qs=%2F%252BYoplLUB5jh6aLSaRqm2A%3D%3D
1 | BQ25172DSGR | BQ25172DSGR | SON50P200X200X80-9N | IC4 | Battery Management 0.8-A, one- to six-cell NiMH stand-alone linear charger in a QFN package | BQ25172DSGR | https://www.arrow.com/en/products/bq25172dsgr/texas-instruments?region=nac |  |  |  | Battery Management 0.8-A | one- to six-cell NiMH stand-alone linear charger in a QFN package | 0.8mm |  | Texas Instruments | BQ25172DSGR |  |  | 595-BQ25172DSGR | https://www.mouser.co.uk/ProductDetail/Texas-Instruments/BQ25172DSGR?qs=tlsG%2FOw5FFgckLJXIVn4PA%3D%3D
1 | BSS138 | BSS138 | SOT95P240X120-3N | Q4 | Compact industry standard SOT-23 surface mount package.; 0.22 A, 50 V. RDS(ON) = 3.5 @ VGS = 10 V. RDS(ON) = 6.0 @ VGS = 4.5 V; Rugged and Reliable.; High density cell design for extremely low RDS(ON). | BSS138 | https://www.arrow.com/en/products/bss138/on-semiconductor?utm_currency=USD&region=europe |  |  |  | Compact industry standard SOT-23 surface mount package.; 0.22 A | 50 V. RDS(ON) = 3.5 @ VGS = 10 V. RDS(ON) = 6.0 @ VGS = 4.5 V; Rugged and Reliable.; High density cell design for extremely low RDS(ON). | 1.2mm |  | onsemi | BSS138 |  |  | 512-BSS138 | https://www.mouser.co.uk/ProductDetail/onsemi-Fairchild/BSS138?qs=HK%252BeIG1iaahCeqBvjB4arg%3D%3D
1 | CP2102N-A02-GQFN28R | CP2102N-A02-GQFN28R | QFN50P500X500X80-29N | IC2 | USB Interface IC USB to UART bridge - QFN28 | CP2102N-A02-GQFN28R | https://www.arrow.com/en/products/cp2102n-a02-gqfn28r/silicon-labs?utm_currency=USD&region=nac |  |  |  | USB Interface IC USB to UART bridge - QFN28 | 0.8mm |  | Silicon Labs | CP2102N-A02-GQFN28R |  |  | 634-CP2102NA02QFN28R | https://www.mouser.co.uk/ProductDetail/Silicon-Labs/CP2102N-A02-GQFN28R?qs=u16ybLDytRag4qKvSH3fTw%3D%3D
2 | CUS08F30 | CUS08F30 | CUS357H3F | D4, D13 | 30 V/0.8 A Schottky Barrier Diode, SOD-323(USC) |  |  |  |  |  | 30 V/0.8 A Schottky Barrier Diode | SOD-323(USC) | 1.15mm |  | Toshiba | CUS08F30 |  |  | N/A | https://www.mouser.co.uk/ProductDetail/Toshiba/CUS08F30?qs=spvbAvdhj5k4Gr60FuQGvg%3D%3D |  |  |  |  |  |  |  |  |  |  |  | https://toshiba.semicon-storage.com/info/lookup.jsp?pid=CUS08F30#documents
1 | DFE252012F-1R0M=P2 | DFE252012F-1R0M=P2 | DFE2HCAH1R0MJ0L | L1 | DFE252012F Series Inductor 1.0uH +/-20% 1008 (2520) | DFE252012F-1R0M=P2 | https://www.arrow.com/en/products/dfe252012f-1r0mp2/murata-manufacturing.html?region=europe |  |  |  | DFE252012F Series Inductor 1.0uH +/-20% 1008 (2520) | 1.2mm |  | Murata Electronics | DFE252012F-1R0M=P2 |  |  | 81-DFE252012F-1R0MP2 | https://www.mouser.co.uk/ProductDetail/Murata-Electronics/DFE252012F-1R0M%3dP2?qs=ty6qhqyUUEtPvXJAIo0Pnw%3D%3D
2 | DMN3065LW-7 | DMN3065LW-7 | SOT65P210X110-3N | Q5, Q8 | Diodes Inc DMN3065LW-7 N-channel MOSFET Transistor, 4 A, 30 V, 3-Pin SOT-323 | DMN3065LW-7 | https://www.arrow.com/en/products/dmn3065lw-7/diodes-incorporated?utm_currency=USD&region=europe |  |  |  | Diodes Inc DMN3065LW-7 N-channel MOSFET Transistor | 4 A | 30 V | 3-Pin SOT-323 | 1.1mm |  | Diodes Incorporated | DMN3065LW-7 |  |  | 621-DMN3065LW7 | https://www.mouser.co.uk/ProductDetail/Diodes-Incorporated/DMN3065LW-7?qs=JtunSoW0QGGjls1HwhS7gQ%3D%3D
1 | DMP2035U | DMP2035U | SOT96P240X115-3N | IC5 | MOSFET, P CH, ESD,-20V,-3.6A, SOT23 |  |  |  |  |  | MOSFET | P CH | ESD | -20V | -3.6A | SOT23 | 1.15mm |  | Diodes Incorporated | DMP2035U |  |  | N/A | https://www.mouser.co.uk/ProductDetail/Diodes-Incorporated/DMP2035U?qs=Wj%2FVkw3K%252BMDmKO9IPsKBeQ%3D%3D
1 | DMP3056L-7 | DMP3056L-7 | SOT96P240X110-3N | Q6 | MOSFET 30V P-Ch Enh Mode 50mOhm -10Vgs -4.3A | DMP3056L-7 | https://www.arrow.com/en/products/dmp3056l-7/diodes-incorporated?region=nac |  |  |  | MOSFET 30V P-Ch Enh Mode 50mOhm -10Vgs -4.3A | 1.1mm |  | Diodes Incorporated | DMP3056L-7 |  |  | 621-DMP3056L-7 | https://www.mouser.co.uk/ProductDetail/Diodes-Incorporated/DMP3056L-7?qs=OVC8WVYZliQTX9kMWW%252B96Q%3D%3D
2 | DMP3068L-7 | DMP3068L-7 | SOT96P240X115-3N | Q1, Q2 | MOSFET 30V P-Ch Enh Mode 72mOhm -10V -3.9A | DMP3068L-7 | https://www.arrow.com/en/products/dmp3068l-7/diodes-incorporated?utm_currency=USD&region=nac |  |  |  | MOSFET 30V P-Ch Enh Mode 72mOhm -10V -3.9A | 1.15mm |  | Diodes Incorporated | DMP3068L-7 |  |  | 621-DMP3068L-7 | https://www.mouser.co.uk/ProductDetail/Diodes-Incorporated/DMP3068L-7?qs=BvpHGKeVh3rIffE3x2yGSw%3D%3D
1 | ESP32-C6-MINI-1-N4 | ESP32-C6-MINI-1-N4 | XCVR_ESP32-C6-MINI-1-N4 | U1 | Check availability |  |  | In Stock |  | https://www.snapeda.com/parts/ESP32-C6-MINI-1-N4/Espressif+Systems/view-part/?ref=eda | 802.15.4 | Bluetooth | WiFi 802.11ax | Bluetooth v5.0 | Zigbee® Transceiver Module 2.4GHz Antenna Not Included Surface Mount |  |  |  |  |  | Espressif Systems |  |  | ESP32-C6-MINI-1-N4 |  |  | SMD-53 Espressif Systems |  |  |  | None |  |  |  |  | https://www.snapeda.com/parts/ESP32-C6-MINI-1-N4/Espressif+Systems/view-part/?ref=snap
1 | FUSB303TMX | FUSB303TMX | X2QFN12 | U2 | Check availability |  |  | In Stock |  | https://www.snapeda.com/parts/FUSB303TMX/Onsemi/view-part/?ref=eda | USB Controller I²C Interface 12-X2QFN (1.6x1.6) |  |  |  |  |  | ON Semiconductor |  |  | FUSB303TMX |  |  | X2QFN-12 ON Semiconductor |  |  |  | None |  |  |  |  | https://www.snapeda.com/parts/FUSB303TMX/Onsemi/view-part/?ref=snap
1 | KPTD-3216SGC | KPTD-3216SGC | KPTD3216SGC | LED1 | LED super bright green 568nm;105mW;water clear;3.2x1.6mm;SMT;reel | KPTD-3216SGC | https://www.arrow.com/en/products/kptd-3216sgc/kingbright |  |  |  | LED super bright green 568nm;105mW;water clear;3.2x1.6mm;SMT;reel | 2mm |  | Kingbright | KPTD-3216SGC |  |  | N/A | https://www.mouser.co.uk/ProductDetail/Kingbright/KPTD-3216SGC?qs=2JU0tDl2GZ1fMmK056gkww%3D%3D
1 | KXTJ3-1057 | KXTJ3-1057 | KIONIX_KXTJ3-1057 | U4 | Check availability |  |  | In Stock |  | https://www.snapeda.com/parts/KXTJ3-1057/Kionix/view-part/?ref=eda | KXTJ3-1057 series Accelerometer | 3 Axis Sensor Evaluation Board |  |  |  |  |  | Kionix Inc. |  |  | KXTJ3-1057 |  |  | LGA-12 Rohm |  |  |  | None |  |  |  |  | https://www.snapeda.com/parts/KXTJ3-1057/Kionix/view-part/?ref=snap
3 | LESD5D5.0CT1G | LESD5D5.0CT1G | LESD5D50CT1G | D1, D2, D3 | Transient Voltage Suppressors for ESD Protection |  |  |  |  |  | Transient Voltage Suppressors for ESD Protection | 0.7mm |  | LRC | LESD5D5.0CT1G
1 | MBR0530 | MBR0530 | SOD3716X135N | D6 | Compact Surface Mount Package with The Same Footprint as Mini-melf; Schottky Rectifier, 0.5A, 30V in SOD-123 Package | MBR0530 | https://www.arrow.com/en/products/mbr0530/on-semiconductor?region=nac |  |  |  | Compact Surface Mount Package with The Same Footprint as Mini-melf; Schottky Rectifier | 0.5A | 30V in SOD-123 Package | 1.35mm |  | onsemi | MBR0530 |  |  | 512-MBR0530 | https://www.mouser.co.uk/ProductDetail/onsemi-Fairchild/MBR0530?qs=VOMQJJE%252BBNniwJKcE3T43Q%3D%3D
2 | MBR230S1F-7 | MBR230S1F-7 | SODFL3518X115N | D5, D7 | Diodes Inc MBR230S1F-7, SMT Schottky Barrier Diode, 30V 2A, 2-Pin SOD123F | MBR230S1F-7 | https://www.arrow.com/en/products/mbr230s1f-7/diodes-incorporated?region=nac |  |  |  | Diodes Inc MBR230S1F-7 | SMT Schottky Barrier Diode | 30V 2A | 2-Pin SOD123F | 1.15mm |  | Diodes Incorporated | MBR230S1F-7 |  |  | 621-MBR230S1F-7 | https://www.mouser.co.uk/ProductDetail/Diodes-Incorporated/MBR230S1F-7?qs=5V6w%252Be2aIqaf4rGxjeeHeQ%3D%3D
1 | MKDV1GCL-AB | MKDV1GCL-AB | SON127P800X600X80-8N | IC9 | Embedded SD Flash |  |  |  |  |  | Embedded SD Flash | 0.8mm |  | MK | MKDV1GCL-AB
1 | MMBT3904 | MMBT3904 | SOT95P230X110-3N | Q7 | 200 MA, NPN, SI, SMALL SIGNAL TRANSISTOR |  |  |  |  |  | 200 MA | NPN | SI | SMALL SIGNAL TRANSISTOR | 1.1mm |  | NXP | MMBT3904
1 | MMBT3906 | MMBT3906 | SOT95P230X110-3N | Q10 | TRANSISTOR,BJT,PNP,40V V(BR)CEO,200MA I(C),SOT-23 65 +150 C ,100 mA,40 V |  |  |  |  |  | TRANSISTOR | BJT | PNP | 40V V(BR)CEO | 200MA I(C) | SOT-23 65 +150 C | 100 mA | 40 V | 1.1mm |  | NXP | MMBT3906 |  |  | N/A | https://www.mouser.co.uk/ProductDetail/NXP-Semiconductors/MMBT3906?qs=55YtniHzbhA96dkd8h4s7Q%3D%3D
1 | MT9700 | MT9700 | SOT95P280X135-5N | IC8 | ic |  |  |  |  |  | ic | 1.35mm |  | Aerosemi | MT9700
33 | NC | JUMPER-SMT_2_NC_TRACE_NO-SILK | SMT-JUMPER_2_NC_TRACE_NO-SILK | JP1, JP2, JP3, JP4, JP5, JP6, JP7, JP8, JP9, JP10, JP13, JP14, JP15, JP16, JP17, JP18, JP19, JP20, JP21, JP22, JP23, JP24, JP25, JP26, JP27, JP28, JP29, JP30, JP31, JP32, JP33, JP34, JP35 | Normally closed trace jumper
1 | NC | JUMPER-SMT_2_NO_NO-SILK | SMT-JUMPER_2_NO_NO-SILK | JP12 | Normally open jumper
1 | NC | R_CHIP-0402(1005-METRIC) | RESC1005X40 | R1 | Resistor Fixed - Generic |  |  |  | Resistor |  |  |  |  |  |  |  |  |  |  |  |  |  |  |  |  |  |  |  |  |  |  |  |  |  | Fixed
1 | PMEG2010AEH | PMEG2010AEH | SODFL3516X120N | D10 | Diode Schottky 20V 1A,PMEG2010AEH NXP PMEG2010AEH Schottky Diode, 1A, 20V, 2-Pin SOD123F |  |  |  |  |  | Diode Schottky 20V 1A | PMEG2010AEH NXP PMEG2010AEH Schottky Diode | 1A | 20V | 2-Pin SOD123F | 1.2mm |  | Nexperia | PMEG2010AEH |  |  | N/A | https://www.mouser.co.uk/ProductDetail/Nexperia/PMEG2010AEH?qs=vHuUswq2%252BswpSqP6MnpTMw%3D%3D
1 | S2B-PH-K-S | S2B-PH-K-S | S2BPHKS | J3 | CONN HEADER R/A 2POS 2MM |  |  |  |  |  | CONN HEADER R/A 2POS 2MM | 4.8mm |  | JST (JAPAN SOLDERLESS TERMINALS) | S2B-PH-K-S
1 | SS34 | SS34 | DIOM5327X244N | D12 | SMD Schottky Diode |  |  |  |  |  | SMD Schottky Diode | 2.438mm |  | KEXIN | SS34
2 | TAJB107K006RNJ | TAJB107K006RNJ | CAPPM3528X210N | C60, C61 | AVX 100 | TAJB107K006RNJ | https://www.arrow.com/en/products/tajb107k006rnj/avx?utm_currency=USD&region=nac |  |  |  | AVX 100 | 2.1mm |  | Kyocera AVX | TAJB107K006RNJ |  |  | 581-TAJB107K006R | https://www.mouser.co.uk/ProductDetail/KYOCERA-AVX/TAJB107K006RNJ?qs=fdqkYiOtZpcsxthKdBMg8Q%3D%3D
1 | TCN75AVOA713 | TCN75AVOA713 | SOIC127P600X175-8N | IC7 | Board Mount Temperature Sensors 2-Wire SER Temp Sens/Ther Mon | TCN75AVOA713 | https://www.arrow.com/en/products/tcn75avoa713/microchip-technology?region=nac |  |  |  | Board Mount Temperature Sensors 2-Wire SER Temp Sens/Ther Mon | 1.75mm |  | Microchip | TCN75AVOA713 |  |  | 579-TCN75AVOA713 | https://www.mouser.co.uk/ProductDetail/Microchip-Technology/TCN75AVOA713?qs=RnzODY3cU8sRlIM3UB0rCw%3D%3D
1 | TLJB227M006R0500 | TLJB227M006R0500 | CAPPM3528X210N | C62 | Tantalum Capacitors - Solid SMD 6.3V 220uF 20% ESR=500 | TLJB227M006R0500 | https://www.arrow.com/en/products/tljb227m006r0500/avx?utm_currency=USD&region=nac |  |  |  | Tantalum Capacitors - Solid SMD 6.3V 220uF 20% ESR=500 | 2.1mm |  | Kyocera AVX | TLJB227M006R0500 |  |  | 581-TLJB227M006R0500 | https://www.mouser.co.uk/ProductDetail/KYOCERA-AVX/TLJB227M006R0500?qs=o28%2FEEzBmj050XjtnkgQxA%3D%3D
2 | TPB1,27 | TPB1,27 | B1,27 | TP3, TP4 | Test pad |  |  |  |  |  |  |  |  |  |  |  |  |  |  |  |  |  |  |  |  | 19
1 | TPS61085DGKR | TPS61085DGKR | SOP65P490X110-8N | IC6 | 18.5V, 2A, 650kHz / 1.2MHz Step-Up DC-DC Converter w/ Forced PWM Mode | TPS61085DGKR | https://www.arrow.com/en/products/tps61085dgkr/texas-instruments?region=europe |  |  |  | 18.5V | 2A | 650kHz / 1.2MHz Step-Up DC-DC Converter w/ Forced PWM Mode | 1.1mm |  | Texas Instruments | TPS61085DGKR |  |  | 595-TPS61085DGKR | https://www.mouser.co.uk/ProductDetail/Texas-Instruments/TPS61085DGKR?qs=59Rn2Bt6jP0PB7IUu7UPlw%3D%3D
1 | TPS62902RPJR | TPS62902RPJR | TPS62902RPJR | IC3 | Switching Voltage Regulators 3-V to 17-V, 2-A, high-efficiency and low IQ buck converter 1.5-mm 2-mm QFN package |  |  |  |  |  | Switching Voltage Regulators 3-V to 17-V | 2-A | high-efficiency and low IQ buck converter 1.5-mm 2-mm QFN package | 1mm |  | Texas Instruments | TPS62902RPJR |  |  | 595-TPS62902RPJR | https://www.mouser.co.uk/ProductDetail/Texas-Instruments/TPS62902RPJR?qs=DRkmTr78QATzfMsnYOTzCQ%3D%3D
1 | TS-1088-AR02016 | TS-1088-AR02016 | TS1088AR02016 | S1 | Tact Switch |  |  |  |  |  | Tact Switch | 2mm |  | XUNPU | TS-1088-AR02016
1 | TS-1103S-C-U (C318914) | TS-1103S-C-U | TS1103SCU | S3 | tact switch 12x12X14 patch cylindrical black knob 260GF stainless steel shrapnel |  |  |  |  |  | tact switch 12x12X14 patch cylindrical black knob 260GF stainless steel shrapnel | 7mm |  | XKB Connectivity | TS-1103S-C-U
1 | U263-241N-4BQC02 | U263-241N-4BQC02 | U263241N4BQC02 | J1 | 3.1TYPE-C connector female 24P upright |  |  |  |  |  | 3.1TYPE-C connector female 24P upright | 6.8mm |  | XKB Connectivity | U263-241N-4BQC02
1 | W25Q128JVSIQ | W25Q128JVSIQ | SOIC127P790X216-8N | IC1 | 128M-bit Serial Flash Memory with uniform 4KB sectors and Dual/Quad SPI | W25Q128JVSIQ | https://www.arrow.com/en/products/w25q128jvsiq/winbond-electronics?utm_currency=USD&region=nac |  |  |  | 128M-bit Serial Flash Memory with uniform 4KB sectors and Dual/Quad SPI | 2.16mm |  | Winbond | W25Q128JVSIQ |  |  | 454-W25Q128JVSIQ | https://www.mouser.co.uk/ProductDetail/Winbond/W25Q128JVSIQ?qs=qSfuJ%252Bfl%2Fd6tLXvPR4fl9w%3D%3D

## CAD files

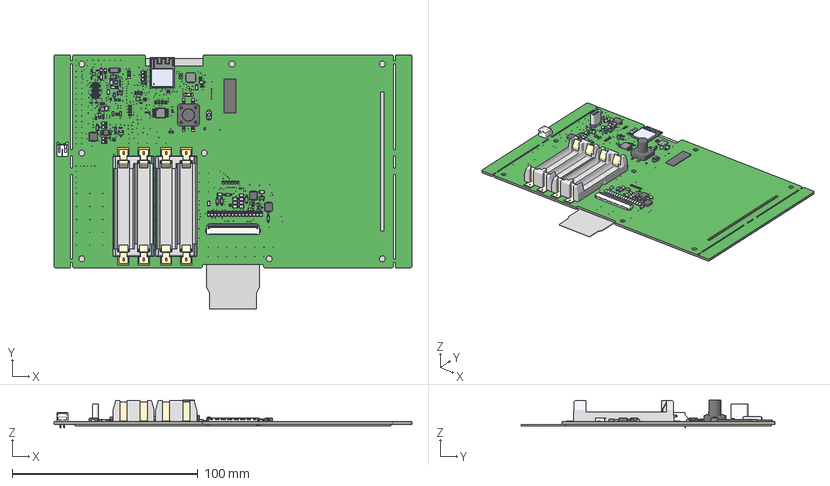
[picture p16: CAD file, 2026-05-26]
paper7/pcb/EPAPER73_V2.3mf
193.0 x 137.2 x 14.9 mm
Kupferlöcher
Körper1 x 164
Körper10 x 5
Körper11 x 5
Körper12 x 5
Körper13 x 5
Körper14 x 5
Körper15 x 3
Körper16 x 3
Körper17 x 2
Körper18 x 2
Körper19 x 2
Körper2 x 28
Körper20 x 2
Körper21 x 2
Körper22 x 2
Körper23 x 2
Körper24 x 2
Körper25 x 2
Körper26 x 2
Körper27 x 2
Körper28 x 2
Körper29 x 2
Körper3 x 23
Körper30 x 2
Körper31 x 2
Körper32 x 2
Körper33 x 2
Körper34 x 2
Körper35 x 2
Körper36 x 2
Körper37 x 2
Körper38 x 2
Körper39 x 2
Körper4 x 16
Körper40 x 2
Körper41 x 2
Körper42 x 2
Körper43 x 2
Körper44 x 2
Körper45 x 2
Körper46 x 2
Körper47 x 2
Körper48 x 2
Körper49 x 2
Körper5 x 15
Körper50 x 2
Körper51 x 2
Körper52 x 2
Körper53 x 2
Körper54 x 2
Körper55
Körper56
Körper57
Körper58
Körper59
Körper6 x 10
Körper60
Körper61
Körper62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

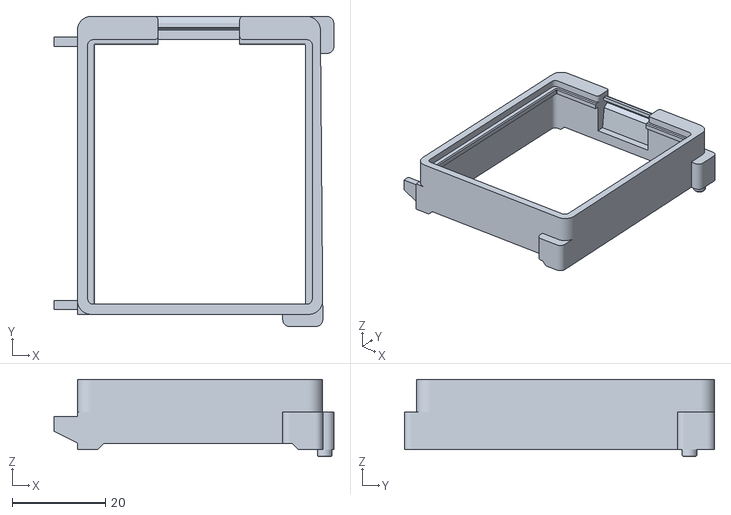
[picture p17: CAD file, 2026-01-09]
paper7/stl/Epaper7-pictureframe-v1.2_BatteryCompartment.stl
60.0 x 66.5 x 16.6

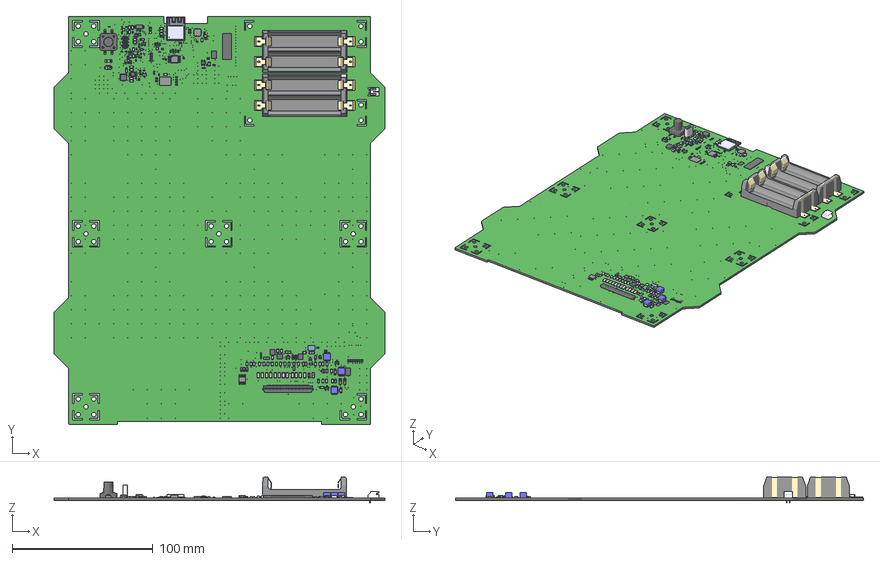
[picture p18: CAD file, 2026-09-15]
paperl/pcb/EPAPER133_V2.3mf
235.0 x 290.0 x 18.3 mm
Kupferlöcher
Körper1 x 225
Körper10 x 4
Körper11 x 4
Körper12 x 4
Körper13 x 4
Körper14 x 4
Körper15 x 2
Körper16 x 2
Körper17
Körper18
Körper19
Körper2 x 33
Körper20
Körper21
Körper22
Körper23
Körper24
Körper25
Körper26
Körper27
Körper28
Körper29
Körper3 x 24
Körper30
Körper31
Körper32
Körper33
Körper34
Körper35
Körper36
Körper37
Körper38
Körper39
Körper4 x 15
Körper40
Körper41
Körper42
Körper43
Körper44
Körper45
Körper46
Körper47
Körper48
Körper49
Körper5 x 12
Körper50
Körper51
Körper52
Körper53
Körper54
Körper55
Körper56
Körper57
Körper58
Körper59
Körper6 x 11
Körper60
Körper61
Körper62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

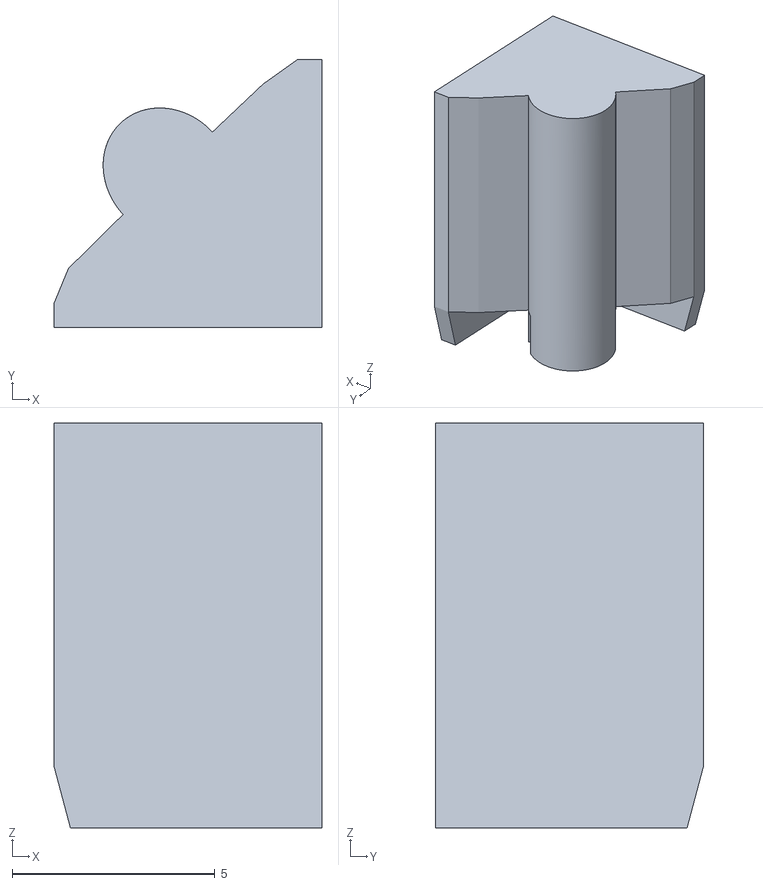
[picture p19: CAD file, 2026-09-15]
paperl/stl/paper-l-Corner.stl
6.61 x 6.61 x 10.00

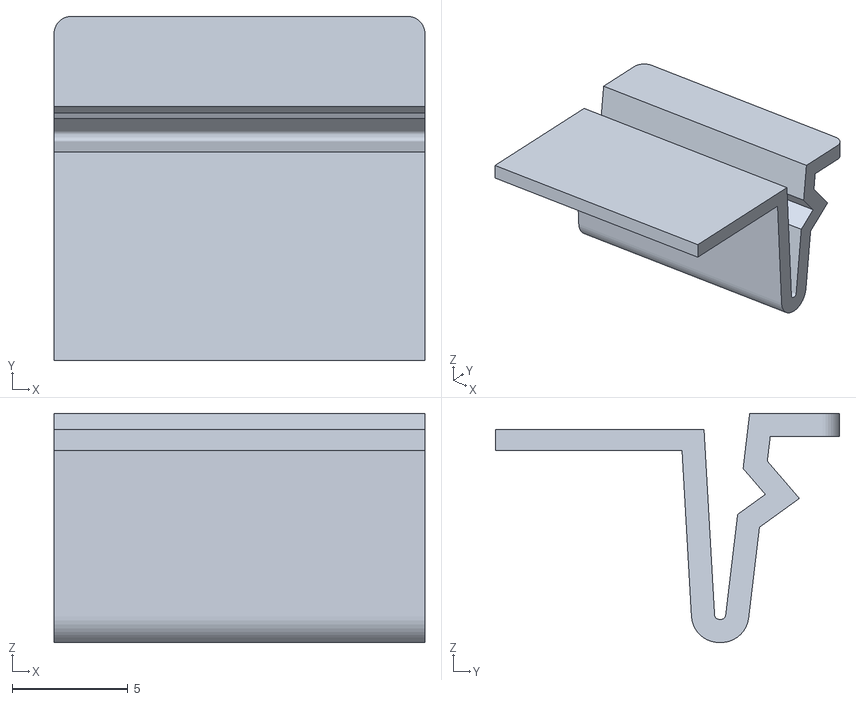
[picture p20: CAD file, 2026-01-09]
paper7/stl/Epaper7-pictureframe-v1.2_BatteryCoverSnap.stl
16.0 x 14.8 x 9.88

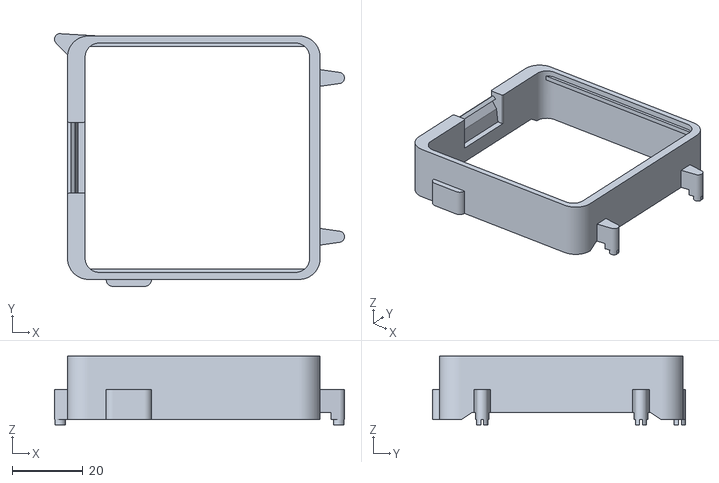
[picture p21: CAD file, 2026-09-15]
paperl/stl/paper-l-BatteryCompartment.stl
82.2 x 71.7 x 19.5

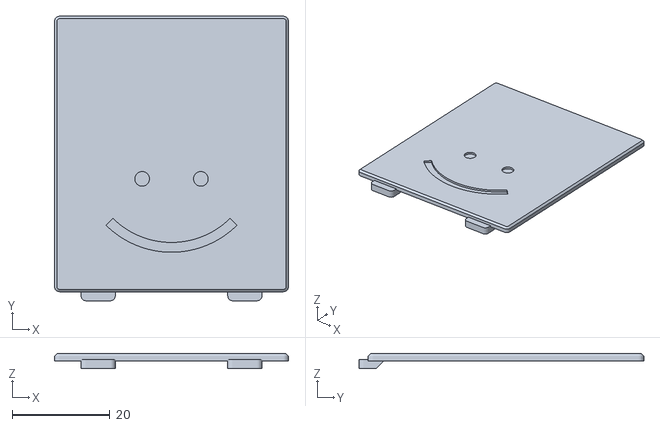
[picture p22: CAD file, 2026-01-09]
paper7/stl/Epaper7-pictureframe-v1.2_BatteryCover.stl
47.9 x 58.2 x 3.00

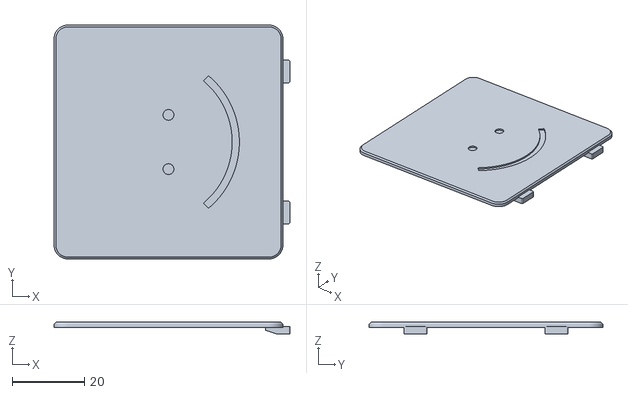
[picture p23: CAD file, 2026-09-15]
paperl/stl/paper-l-BatteryCover.stl
65.3 x 64.7 x 3.20

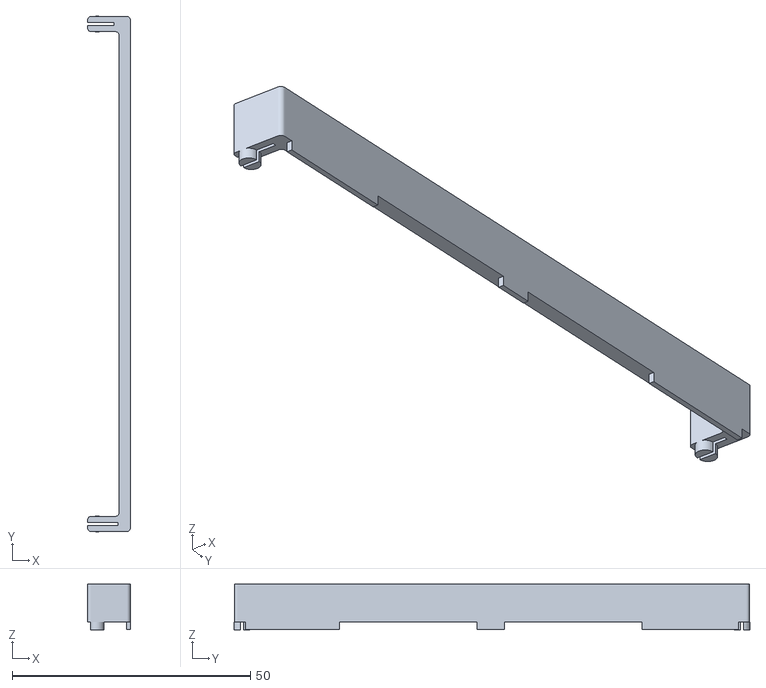
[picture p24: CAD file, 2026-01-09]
paper7/stl/Epaper7-pictureframe-v1.2_DistanceTop.stl
8.95 x 108.4 x 9.60

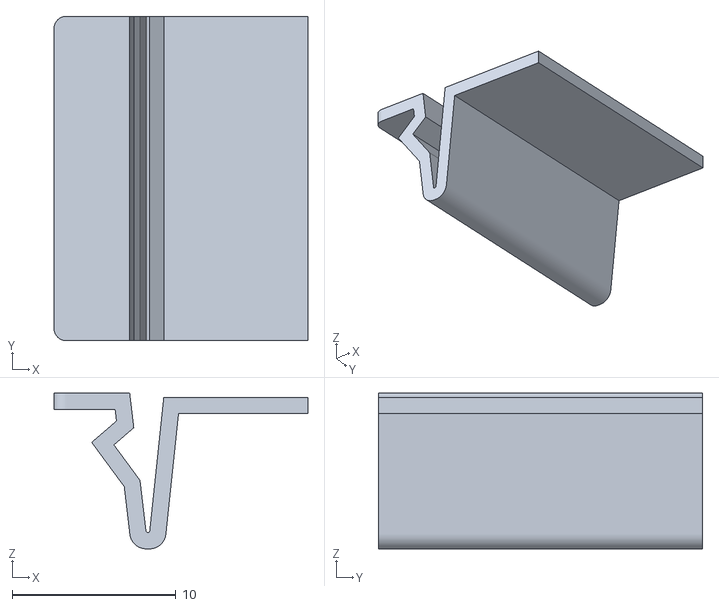
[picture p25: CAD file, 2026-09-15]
paperl/stl/paper-l-Spring.stl
15.5 x 19.8 x 9.50

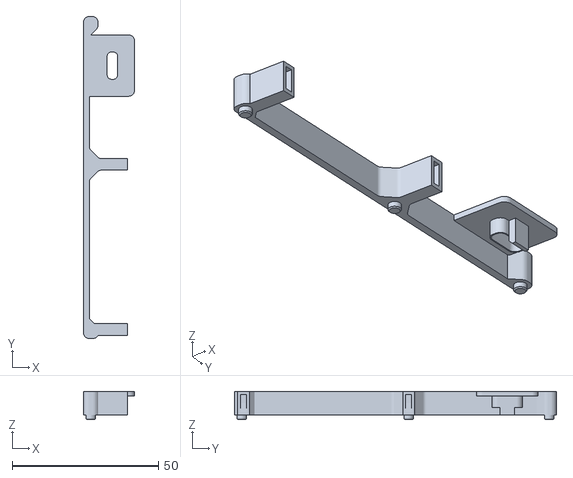
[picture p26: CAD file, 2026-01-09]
paper7/stl/Epaper7-pictureframe-v1.2_DistanceBottom.stl
17.5 x 110.0 x 9.60

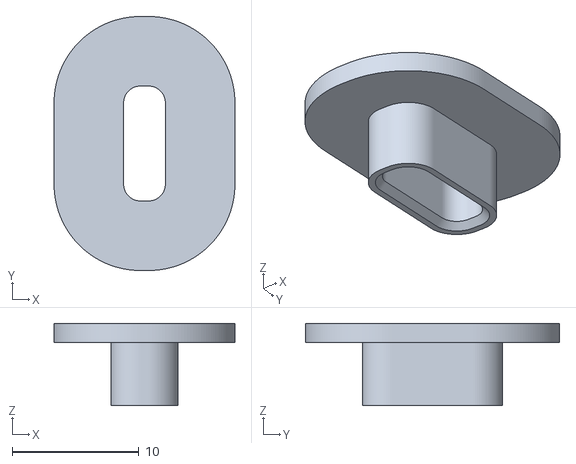
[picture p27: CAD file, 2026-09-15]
paperl/stl/paper-l-USBHolder.stl
14.3 x 20.1 x 6.50

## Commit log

2025-11-10 docs(readme): added pictures for each cad file
2025-11-23 feat(laser): added laser cut files
2026-01-09 feat(stl): added stl files
    [Epaper7-pictureframe-v1.2_BatteryCompartment.stl, Epaper7-pictureframe-v1.2_BatteryCover.stl, Epaper7-pictureframe-v1.2_BatteryCoverSnap.stl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]
2026-05-26 feat(pcb) add openpaper 7 manufacturing data
    [EPAPER73_V2.3mf, epaper-bom-V2.xlsx, epaper-pp-V2.xlsx]
2026-06-13 feat(readme): add PCB design files and manufacturing exports for Paper 7
2026-09-14 feat(hardware): add OpenPaper L design and manufacturing files
    [EPAPER133_V2.3mf, EPAPER133_V2.csv, PnP_EPAPER133_V2_front.csv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]
2026-09-14 chore(hardware): normalize schematic file permissions
2026-09-15 docs(hardware): update README for OpenPaper L with improved Fusion CAD image descriptions and formatting
2026-09-21 fix(pcb) paper 7 update voltage divider to production values
